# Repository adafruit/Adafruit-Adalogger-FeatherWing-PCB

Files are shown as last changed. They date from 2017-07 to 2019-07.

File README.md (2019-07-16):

## Adafruit FeatherWing - RTC + SD Add-on For All Feather Boards PCB

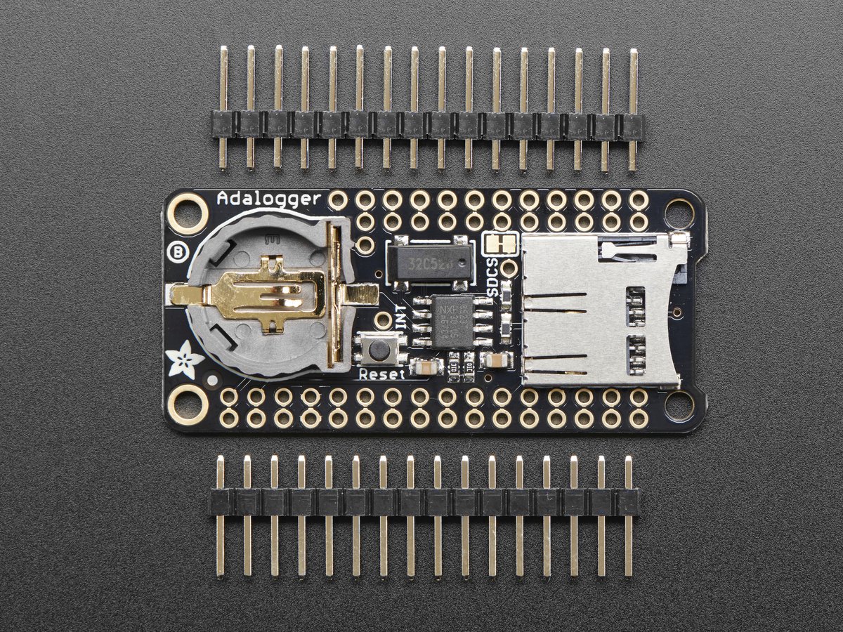
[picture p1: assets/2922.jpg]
<a href="http://www.adafruit.com/products/2922"><br/>
Click here to purchase one from the Adafruit shop</a>

PCB files for the Adafruit FeatherWing - RTC + SD Add-on For All Feather Boards. Format is EagleCAD schematic and board layout
* https://www.adafruit.com/product/2922

### Description

A Feather board without ambition is a Feather board without FeatherWings! This is the **Adalogger FeatherWing**: it adds both a battery-backed Real Time Clock and micro SD card storage to any Feather main board. Using our [Feather Stacking Headers](https://www.adafruit.com/products/2830) or [Feather Female Headers](http://www.adafruit.com/products/2886) you can connect a FeatherWing on top of your Feather board and let the board take flight!

[Check out our range of Feather boards here.](https://www.adafruit.com/feather)

This FeatherWing will make it real easy to add datalogging to any of our existing Feathers. You get both an I2C real time clock (PCF8523) with 32KHz crystal and battery backup, and a microSD socket that connects to the SPI port pins (+ extra pin for CS). **Tested and works great with all of our Feathers.**

**Does not come with a micro SD card. A CR1220 coin cell is required to use the RTC battery-backup capabilities!** We don't include one by default, to make shipping easier for those abroad, [but we do stock them so pick one up or use any CR1220 you have handy](https://www.adafruit.com/products/380). If you're not using the RTC part of the FeatherWing, a battery is not required.[If you need a precision RTC, check out our DS3231 FeatherWing](https://www.adafruit.com/products/3028)

For pinouts, wiring and code example that will run on all Feathers, [check out the tutorial guide which we keep updated as new Feathers come out. It has more information including diagrams, example code for both Arduino and CircuitPython, pinouts, and more!](http://learn.adafruit.com/adafruit-adalogger-featherwing)

### License

Adafruit invests time and resources providing this open source design, please support Adafruit and open-source hardware by purchasing products from [Adafruit](https://www.adafruit.com)!

Designed by Limor Fried/Ladyada for Adafruit Industries.

Creative Commons Attribution/Share-Alike, all text above must be included in any redistribution. See license.txt for additional details.

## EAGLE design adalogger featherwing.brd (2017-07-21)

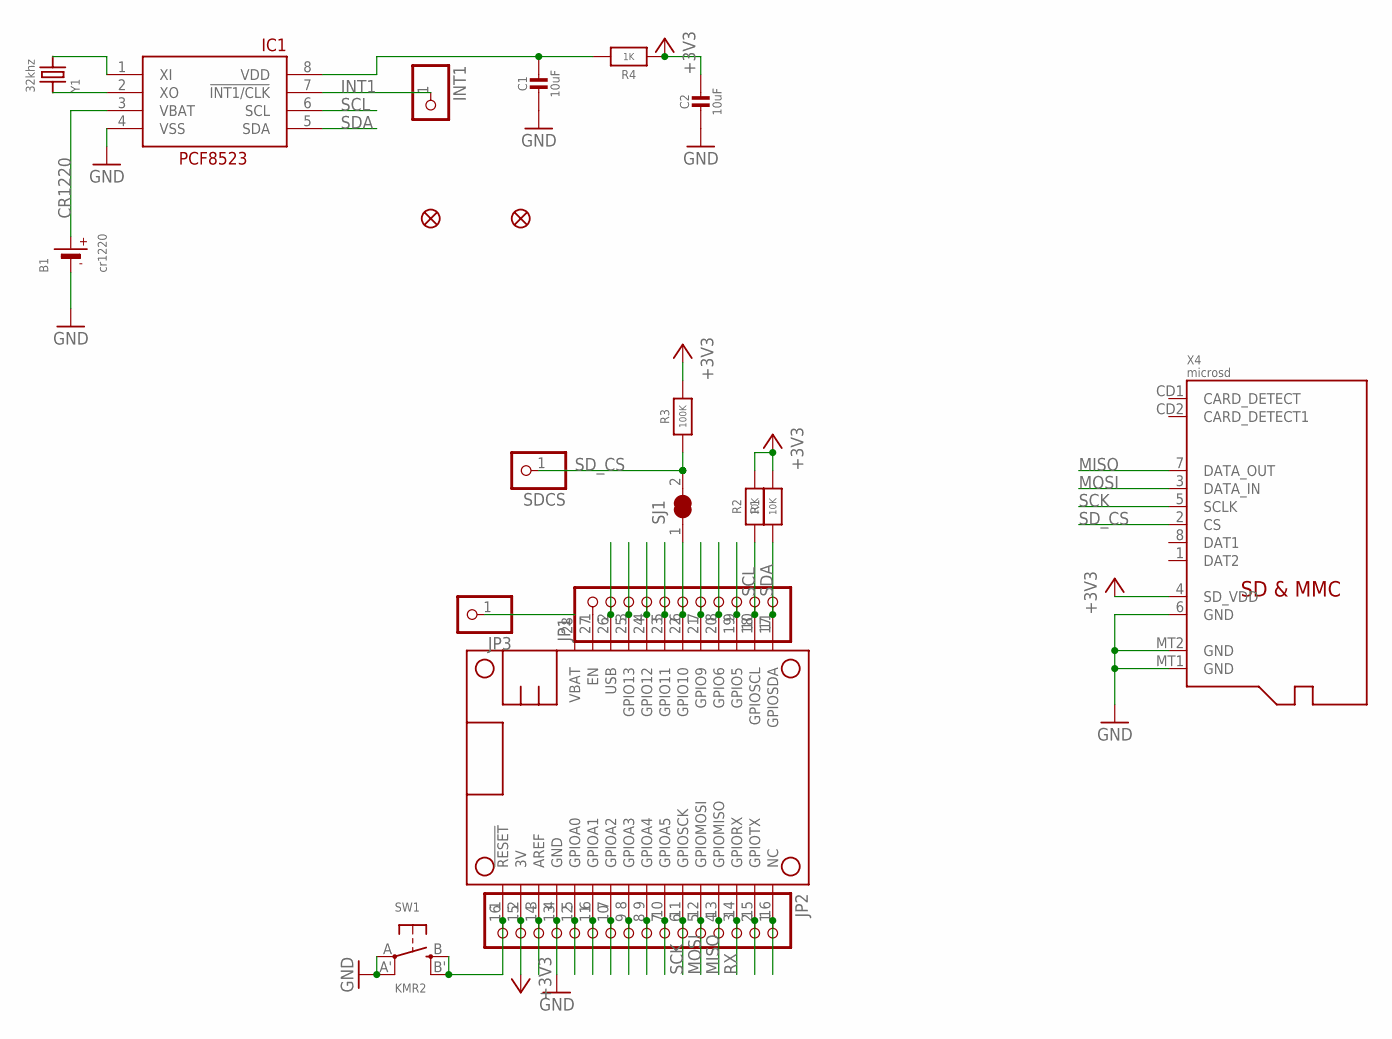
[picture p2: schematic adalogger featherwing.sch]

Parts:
B1: cr1220; CR1220-2
C1, C2: 10uF; 0805-NO
FID1, FID2: FIDUCIAL_1MM
IC1: PCF8523T; SOIC8_150MIL
INT1: HEADER-1X1ROUND; 1X01_ROUND
JP1: HEADER-1X11; 1X11_ROUND
JP2: HEADER-1X16ROUND; 1X16_ROUND
JP3: HEADER-1X1ROUND; 1X01_ROUND
MS1: FEATHERWING_NODIM
R1, R2: 10K; 0603-NO
R3: 100K; 0603-NO
R4: 1K; 0603-NO
SDCS: HEADER-1X1ROUND; 1X01_ROUND
SJ1: SOLDERJUMPER_CLOSED; SOLDERJUMPER_CLOSEDWIRE
SW1: KMR2; BTN_KMR2_4.6X2.8
X4: microsd; MICROSD
Y1: 32khz; CRYSTAL_8X3.8

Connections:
+3V3: C2.1, JP2.15, MS1.2 (3V), R1.2, R2.2, R3.2, R4.1, X4.4 (SD_VDD)
A: JP2.12, MS1.5 (GPIOA0)
AREF: JP2.14, MS1.3 (AREF)
B: JP2.11, MS1.6 (GPIOA1)
C: JP2.10, MS1.7 (GPIOA2)
CR1220: B1.+, IC1.3 (VBAT)
CS: JP1.6, MS1.22 (GPIO10), SJ1.1
D: JP2.9, MS1.8 (GPIOA3)
E: JP2.8, MS1.9 (GPIOA4)
EN: JP1.1, MS1.27 (EN)
F: JP2.7, MS1.10 (GPIOA5)
G: JP2.1, MS1.16 (NC)
GND: B1.-, C1.2, C2.2, IC1.4 (VSS), JP2.13, MS1.4 (GND), SW1.A, SW1.A' (P1), X4.6 (GND), X4.MT1 (GND), X4.MT2 (GND)
H: JP1.9, MS1.19 (GPIO5)
I: JP1.8, MS1.20 (GPIO6)
INT1: IC1.7 (!INT1/CLK), INT1.1
J: JP1.7, MS1.21 (GPIO9)
L: JP1.5, MS1.23 (GPIO11)
M: JP1.4, MS1.24 (GPIO12)
MISO: JP2.4, MS1.13 (GPIOMISO), X4.7 (DATA_OUT)
MOSI: JP2.5, MS1.12 (GPIOMOSI), X4.3 (DATA_IN)
N: JP1.3, MS1.25 (GPIO13)
unnamed: C1.1, IC1.8 (VDD), R4.2
unnamed: IC1.1 (XI), Y1.P$4 (2)
unnamed: IC1.2 (XO), Y1.P$1 (1)
RESET: JP2.16, MS1.1 (!RESET), SW1.B (S), SW1.B' (S1)
RX: JP2.3, MS1.14 (GPIORX)
SCK: JP2.6, MS1.11 (GPIOSCK), X4.5 (SCLK)
SCL: IC1.6 (SCL), JP1.10, MS1.18 (GPIOSCL), R2.1
SDA: IC1.5 (SDA), JP1.11, MS1.17 (GPIOSDA), R1.1
SD_CS: R3.1, SDCS.1, SJ1.2, X4.2 (CS)
TX: JP2.2, MS1.15 (GPIOTX)
USB: JP1.2, MS1.26 (USB)
VBAT: JP3.1, MS1.28 (VBAT)

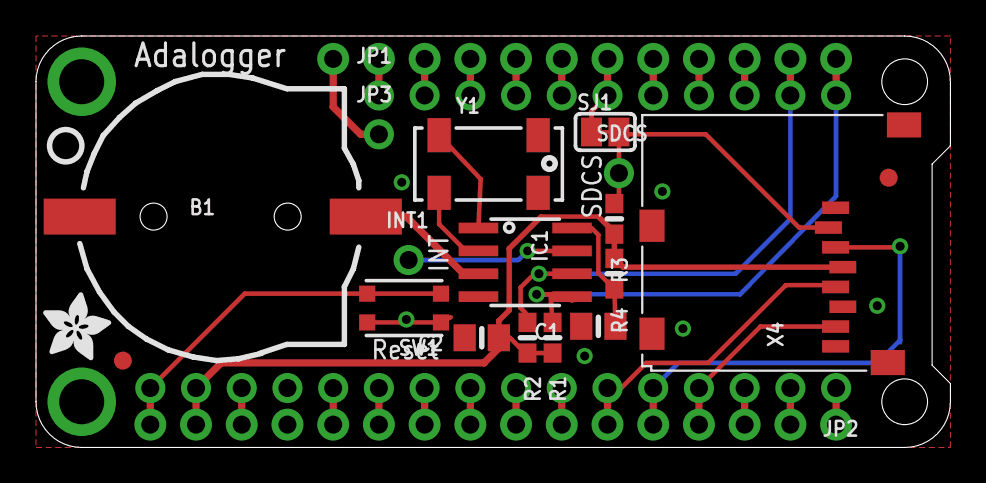
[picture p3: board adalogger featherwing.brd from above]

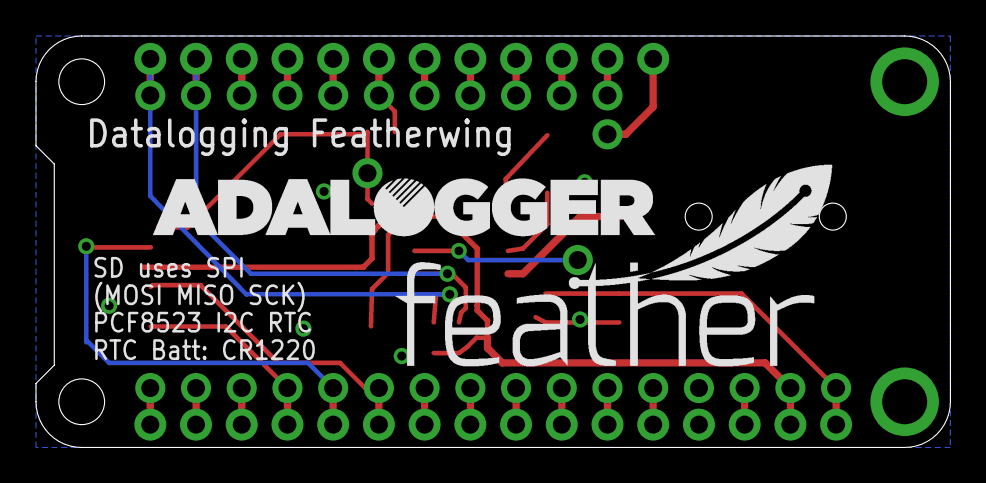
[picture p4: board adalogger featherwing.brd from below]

Board: 2 copper layers, 50.8 x 22.9 mm, 24 parts (2 on the bottom side), 34 nets.

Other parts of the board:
U$2: FEATHERLOGO
U$3: ADALOGGER_LOGO
U$4: ADAFRUIT_3.5MM
U$5: PCBFEAT-REV-040

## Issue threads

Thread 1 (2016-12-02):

Lost clock on power loss

ericbaril72, 2016-12-02:
Hello Adafruit,
after checking into most forums and validating a few theories on the facts at end--> When used with the Adafruit M0-Winc1500 feather board the PCF8523 RTC  looses time on power loss ( either USB or Lithium Battery, not the Coin CR cell of course ).

I decided to use an external RTC mainly to avoid loosing time in case of software errors ( WDT reset, manual reset, accidental battery unplug,)  Arduino SAMD21 Bootloader does not maintain RTC operation ( will create large offset over time )

--> Solution as per PCF spec sheet and validated on 10+ boards being continously resetted, re flashed, unpowered AND wearing ESD prone clothing )
Page 54 of the spec sheet -->  1k resistor +3.3uF  capacitor at the inputVdd of the PCF8523.

Sould I EAGLE -- Clone / update / Pull request ? or do you beleive the PCB should stay as-is ?
      <0.06$ price increase including pick-and-place.

Stop "loosing time" even when unplugging power while write on SDcard

ladyada, 2016-12-02:
i dont see why it *wouldnt* lose time on power loss? the RTC requires a coin cell. are you not including the coin cell?

ericbaril72, 2016-12-03:
Come On ! Yes the coin cell is brand new, reputable brand and voltage is measured.

The problem is with the rate of fall of Vdd.
I am using the adalogger along the M0-feather Winc1500.

On power loss, vdd falls very quickly during operation ( M0, Sd card, ...) and pcf8523 doesn't switch to coin cell operation fast-enough.

It may work fine on other Feather MCU operation.  The proposed HW change is based on the PCF spec sheet recommandation and would increase the reliability of the adalogger RTC for a wider usage set.

I decided to use an external RTC even if M0 has an integrated one.  Way too many things can go wrong with integrated RTC clocks ( based on many years of professional HW designs) , and the Arduino Core has many ´restrictions', boot loader mode does not maintain internal RTC and pretty ´tough' to make coin-cell operation compatible.

At this point, modifying the adalogger to add CAP and resistor is a bit of a pain based on trace location.

IF not adding the extra resistor and CAP, at the very least, a footprint ready solution would be better. ( resistor footprint with cut-ready joining trace like the pin 10 SD_CS  and Capacitor footprint on the VDd pin of the PCF ) of course the current 3.3v trace powering the SD +decoupling Cap would need to be adjusted.

I will need around 50 loggers first half 2017 current modding ( cut 2 places , re-route 3.3v for SD and decoupling Cap, add large cap&persist or takes too long)
Thanks for considering

ladyada, 2016-12-03:
ok that makes sense. we'll check it out. no ETA!

ericbaril72, 2016-12-14:
I have the files ready with added 1k + CAP ( schematic change + new pcb layout ).
Let me know how to send Pull-request since this repo is "locked"

ericbaril72, 2017-05-24:
Hello there,
I can validate the results if you like the new gerbers.
I need to build 50pcs and manual rework is a pain ...

ladyada, 2017-05-24:
hiya we've updated the design, the next version of the wing (when https://www.adafruit.com/product/2922 is back in stock) will have this correction!

ericbaril72, 2017-05-24:
Did I have anything to do with it or was it allready done ? I didn't/don't
see commits since >1 year

Eric

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

ladyada, 2017-05-24:
yes! our community let us know about the bug and once we were able to verify it we updated our design :) it'll be in the shop soon (maybe a couple weeks)

sdaugherty1, 2017-06-13:
Hello there, I recently purchased 2 data loggers for a development project.  Using Mega2560.  I'm having a reoccurring issue with losing accurate time after power cycling.  The correct time may stay for 1, 2 maybe even 3 times but eventually, the accurate time is lost by the RTC.  I started by replicating the hardware on a 2nd build, had the same issue, then started dropping shields off until the only thing left is the logger itself logging a timestamp.  Still have the same issue.  Could the issue in this thread be related?  If so, is there anything that I can do to correct it?

ericbaril72, 2017-06-14:
Which Datalogger are your refering to ?
I am guessing your are using this one:
       https://learn.adafruit.com/assets/35519

check which board revision you have .... mainly if the RTC chip is the
PCF8523.

I am using the FEATHER wing version : https://www.adafruit.com/product/2922
which uses the PCF8523 also ...

The PCB of the feather was recently modified to put an RC filter on the RTC
  vdd pin.
If the 3.3V drops too quickly, the battery switch-over is not perfect.

You can try adding a larger Capacitor on the 3.3V rail of the RTC chip but
if something runs on the 3.3V when unplugging ... it mght still be too
quick of a drop.
Then, the series resistor will be mandatory -->    1k resistor in series
between the main 3.3V rail and the RTC vdd pin + a 10uF cap on the RTC vdd
pin.

[image: image.png]

On Mon, Jun 12, 2017 at 9:13 PM sdaugherty1 <notifications@github.com>
wrote:

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

sdaugherty1, 2017-06-25:
Hello Eric and thanks so much for your reply.  Your correct, I'm using https://learn.adafruit.com/assets/35519 with RTC PCF8523.  I continued to try other options and have exhausted everything I can think / has been recommended with the exception of cutting etches and trying to implement your fix.  Honestly, I would have tried your option much sooner but older eyes kinda make etchwork.....iffy.  Either your image didn't make it through or I'm overlooking the proper way to view it but think I understand the intent and layout of your solution.  I'll advise once I have the opportunity to give the fix a shot on one of the shields.....or end up chucking it cause I've mangled it :)  Thanks again!

Closed 2016-12-03.

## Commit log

2017-07-21 update with RC filter
    [adalogger featherwing.brd, adalogger featherwing.sch]
2019-07-16 updated to use cookiecutter for pcb repos
